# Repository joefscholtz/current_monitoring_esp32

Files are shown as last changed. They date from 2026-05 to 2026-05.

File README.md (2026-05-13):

# current_monitoring_esp32

Modular firmware project in PlatformIO and hardware design in KiCad using ESP32 and ESP-IDF framework for measuring current and detecting leakage using CT sensors, publishing the data via MQTT through Wifi ( and Ethernet, but not yet fully implemented ). For more informatation on design decisions consult the `docs` directory.

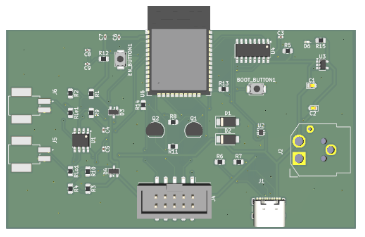
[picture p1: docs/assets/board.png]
Custom ESP32-WROOM-32E Board


## Project structure

```
.
├── .github/workflows/          # CI/CD
├── app/                        # Two alternatives to consume the library
│   ├── bare_metal/             # Simple Super-Loop implementation
│   └── rtos/                   # RTOS Task-based
├── components/                 # Library ESP-IDF style components
│   └── current_monitor/        # RMS, Differential math, Calibration
│   └── network_manager/        # Wifi, Ethernet and MQTT
├── docs/                       # Documentation
├── kicad/                      # KiCad files
│   └── current_monitor_board/  # KiCad project
│   └── mods/                   # KiCad libraries
├── scripts/                    # Scripts for the project
├── test/                       # Unit tests for the monitor library
├── platformio.ini              # Multi-environment config
├── wokwi.toml                  # Simulation config for ESP32 + Sensors
└── diagram.json                # Wokwi hardware layout
```

## Installation

### With Docker

Requirements:

- Docker
- Docker Compose
- just (Optional)

using just:

```bash
just dev init
```

without just

```bash
DOCKER_COMPOSE_SERVICE=current_monitoring_esp32-app

docker-compose run --rm $DOCKER_COMPOSE_SERVICE just init
```

### Without Docker:

Requirements:

- uv (Python manager)
- PlatformIO CLI
- Wokwi (Optional, needed for simulation)
- just (Optional)

using just:

```bash
just init
```

without just

```bash
uv sync
uv run pio run -t compiledb
```

### Git hooks

using uv and just

```bash
just pre-commit-init
```

using only uv

```bash
uv run pre-commit install --hook-type pre-commit --hook-type pre-push
```

and it can also be installed using only Python.

## Build

### With Docker

using just:

```bash
just dev build
```

without just

```bash
DOCKER_COMPOSE_SERVICE=current_monitoring_esp32-app

docker-compose run --rm $DOCKER_COMPOSE_SERVICE just build
```

### Without Docker:

using just:

```bash
just build
```

without just

```bash
uv run pio run -e bare_metal -e rtos
```

## Flash

...

## TODO

### current_monitor:

- [x] Acquisition interval missed
- [x] Convert raw into voltage
- [x] Calibration
- [ ] Move pin definitions to Kconfig
- [ ] Check `MAX_DIGI_VALUE`

### mqtt:

### App:

### Flash

- [ ] Add flash scripts
- [ ] efuse
- [ ] self-contained flash script

### Docs:

- [x] Hardware mapping
- [x] C4 model

### KiCad

- [ ] MQTT thru Ethernet

### Other:

- [x] Test with PlatformIO IDE
- [ ] Run Tests without `static inline` functions

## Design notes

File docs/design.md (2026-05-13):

## Design Documentation

## 1. System Architecture

```mermaid
C4Container
    title Container & Hardware Interaction Diagram

    %% Physical Hardware Layer
    System_Boundary(hw, "Physical Hardware") {
        Container(leakage_ct, "CT 2000:1 (Leakage)", "Hardware", "GPIO 34 (ADC1_CH6) + 22k Burden")
        Container(load_ct, "CT 1000:1 (Load)", "Hardware", "GPIO 35 (ADC1_CH7) + 100R Burden")
        Container(eth_chip, "DISABLED: ENC28J60 (Ethernet)", "SPI Peripheral", "GPIO 18, 19, 23 (VSPI)")
    }

    %% Firmware Layer
    Container_Boundary(esp32, "ESP32 Firmware") {

        Container_Boundary(core1, "Core 1 (Sensing)") {
            Container(sensor_task, "Sensor Task", "FreeRTOS", "vTaskDelayUntil (300ms frequency)")
            Container(cm_comp, "Current Monitor", "IDF Component", "ADC1 Drivers + RMS Engine")
        }

        Container_Boundary(core0, "Core 0 (Networking)") {
            Container(network_task, "Network Task", "FreeRTOS", "Asynchronous MQTT Client")
            Container(nm_comp, "Network Manager", "IDF Component", "WiFi/ETH/MQTT Handlers")
        }

        ContainerDb(queue, "Data Queue", "FreeRTOS Queue", "Current_readings_t (inc. Timestamp)")
    }

    %% Relationships
    Rel(leakage_ct, cm_comp, "Analog Signal", "Voltage (0-3.3V)")
    Rel(load_ct, cm_comp, "Analog Signal", "Voltage (0-3.3V)")
    Rel(sensor_task, cm_comp, "Reads Raw/RMS", "API Call")
    Rel(sensor_task, queue, "Pushes Data", "Queue Send (Non-blocking)")

    Rel(queue, network_task, "Pops Data", "Queue Receive (Blocking)")
    Rel(network_task, nm_comp, "Triggers Pub", "API Call")
    Rel(nm_comp, eth_chip, "SPI Commands", "VSPI Bus")
```

## 2. Hardware Mapping:

The system is designed for the ESP32-WROOM-32 (30 or 38 pin DevKit). The following pins were selected based on their peripheral capabilities (ADC1 vs ADC2) availability.

| Component | GPIO | Peripheral | Function | Logic / Signal |
| --- | ---- | --- | --- | --- |
| Leakage CT | 34 | ADC1_CH6 | Analog Input | AC signal + 1.65V Bias |
| Load CT | 35 | ADC1_CH7 | Analog Input | AC signal + 1.65V Bias |
| V_Ref Monitor | 32 | ADC1_CH4 | Analog Input | 1.65V DC Mid-rail (Calibration) |

## 3. Design Decisions

### 3.1 RMS Sampling Strategy

To meet the 300ms maximum interval requirement, the firmware implements a high-frequency sampling window:

- Sampling Frequency: ~5-10kHz per channel to accurately capture 60Hz waveforms.
- RMS Calculation: Discrete-time True RMS calculation is performed: $V_{rms} = \sqrt{\frac{1}{N} \sum_{i=1}^{N} (v_i - V_{offset})^2}$
- Fixed Frequency: Using `vTaskDelayUntil` ensures the 300ms deadline is strictly met regardless of calculation overhead, avoiding drift.

### 3.2 Noise Handling

- Hardware Offset: A 1.65V DC bias is applied to the CT signal to allow the ESP32 (0-3.3V range) to sample the AC negative half-cycle.
- Software Filtering:
  - Deadzone: A small software threshold is applied to eliminate "ghost" readings caused by ADC noise floor.
  - Averaging: Multiple samples are accumulated per window to smooth out transient spikes.
  - Hardware Calibration: ADC calibration to mitigate chip-to-chip gain errors.

### 3.3 Software Architecture

- Modular Component Architecture: Logic is segregated into reusable, standalone components (`current_monitor`, `network_manager`) to minimize coupling and facilitate parallel testing.
- Provider/Consumer Model: The `apps/` act as consumers of the `components/` provider library. This allows the same hardware-interfacing code to be reused across different execution models (Bare-Metal Super-Loop vs. RTOS Preemptive Tasks).
- Opaque Handle Pattern: By using pointer-based handles for component initialization and interaction, the internal structures remain protected from the application layer, reducing the risk of accidental memory corruption.
- Decoupling (Dual-Core): Sampling is pinned to Core 1 to ensure zero jitter.
- Networking (WiFi/MQTT) is pinned to Core 0 to handle the non-deterministic TCP/IP stack.
- Unified Identity: Both Wi-Fi and Ethernet (Ethernet not fully implemented) use the internal Factory MAC as the MQTT Client ID, ensuring the backend treats the device as a single entity regardless of the physical connection.

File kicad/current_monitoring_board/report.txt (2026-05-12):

Annotated USB_C_Receptacle_USB2.0_16P as J1.
Annotated 100k as R5.
Annotated 100k as R4.
Annotated 100k as R3.
Annotated 100k as R2.
Annotated 100k as R1.
Annotated S8050 as Q2.
Annotated S8050 as Q1.
Annotated Microsemi_FlashPro-JTAG-10 as J4.
Annotated RJ45_Hanrun_HR911105A_Horizontal as J3.
Annotated CUI_PD-30 as J2.
Annotated 5.1k as R6.
Annotated BAT54S as D4.
Annotated BAT54S as D3.
Annotated SS14 as D2.
Annotated SS14 as D1.
Annotated 100nF as C9.
Annotated 100uF as C8.
Annotated 100nF as C7.
Annotated 22uF as C6.
Annotated 10nF as C5.
Annotated 10nF as C4.
Annotated TS-1088-AR02016 as S1.
Annotated ASV-50.000MHz as Y1.
Annotated ESP32-WROOM-32E as U6.
Annotated LAN8720A as U5.
Annotated OPA2333xxD (unit C) as U1C.
Annotated CH340C as U4.
Annotated AP2112K-3.3 as U3.
Annotated USBLC6-2P6 as U2.
Annotated OPA2333xxD (unit B) as U1B.
Annotated OPA2333xxD (unit A) as U1A.
Annotated TS-1088-AR02016 as S2.
Annotated 10u as C3.
Annotated 100 as RLo1.
Annotated 22k as RLe1.
Annotated 10k as R14.
Annotated 100 as R13.
Annotated 10k as R12.
Annotated 10k as R11.
Annotated 100 as R10.
Annotated 100 as R9.
Annotated 10k as R8.
Annotated 5.1k as R7.
Annotated GND as #PWR012.
Annotated GND as #PWR022.
Annotated +5V as #PWR021.
Annotated +5V as #PWR020.
Annotated +3.3V as #PWR019.
Annotated +3.3V as #PWR018.
Annotated GND as #PWR017.
Annotated GND as #PWR016.
Annotated +3.3V as #PWR015.
Annotated GND as #PWR014.
Annotated GND as #PWR013.
Annotated +5V as #PWR023.
Annotated GND as #PWR011.
Annotated +5V as #PWR010.
Annotated GND as #PWR09.
Annotated +5V as #PWR08.
Annotated +5V as #PWR07.
Annotated GND as #PWR06.
Annotated +5V as #PWR05.
Annotated GND as #PWR04.
Annotated +3.3V as #PWR03.
Annotated GND as #PWR02.
Annotated GND as #PWR034.
Annotated TCJB226M025R0150E as C2.
Annotated TCJB226M025R0150E as C1.
Annotated GND as #PWR042.
Annotated +3.3V as #PWR041.
Annotated GND as #PWR040.
Annotated GND as #PWR039.
Annotated GND as #PWR038.
Annotated +3.3V as #PWR037.
Annotated GND as #PWR036.
Annotated +3.3V as #PWR035.
Annotated +3.3V as #PWR01.
Annotated +3.3V as #PWR033.
Annotated GND as #PWR032.
Annotated +3.3V as #PWR031.
Annotated GND as #PWR030.
Annotated GND as #PWR029.
Annotated GND as #PWR028.
Annotated +5V as #PWR027.
Annotated GND as #PWR026.
Annotated GND as #PWR025.
Annotated GND as #PWR024.
Annotation complete.

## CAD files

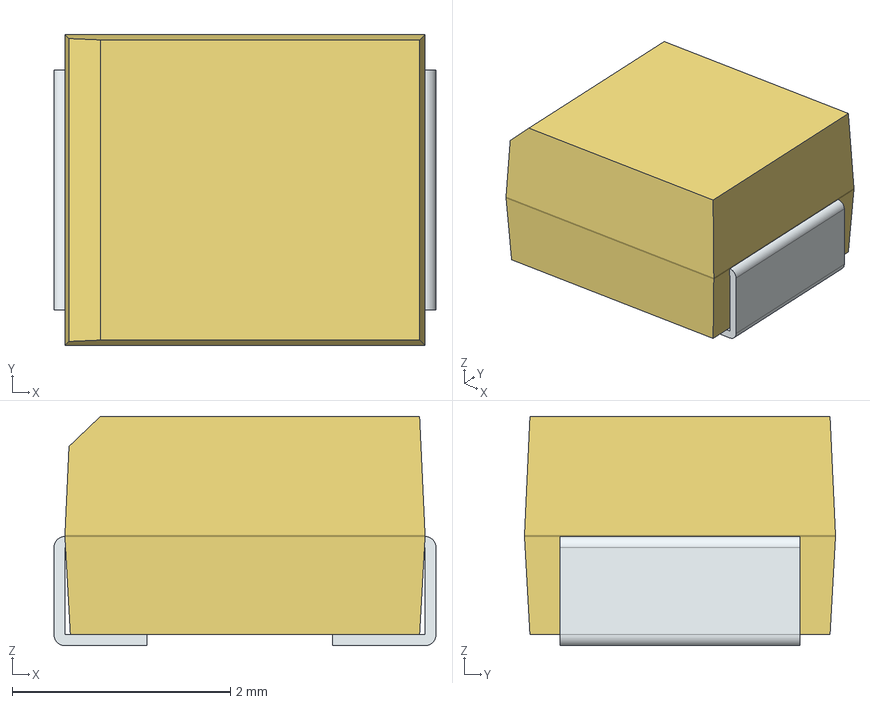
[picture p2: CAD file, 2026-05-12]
kicad/mods/TCJB226M025R0150E/3D/TCJB226M025R0150E.stp
3.50 x 2.85 x 2.10 mm
FilletPin1
FilletPin2

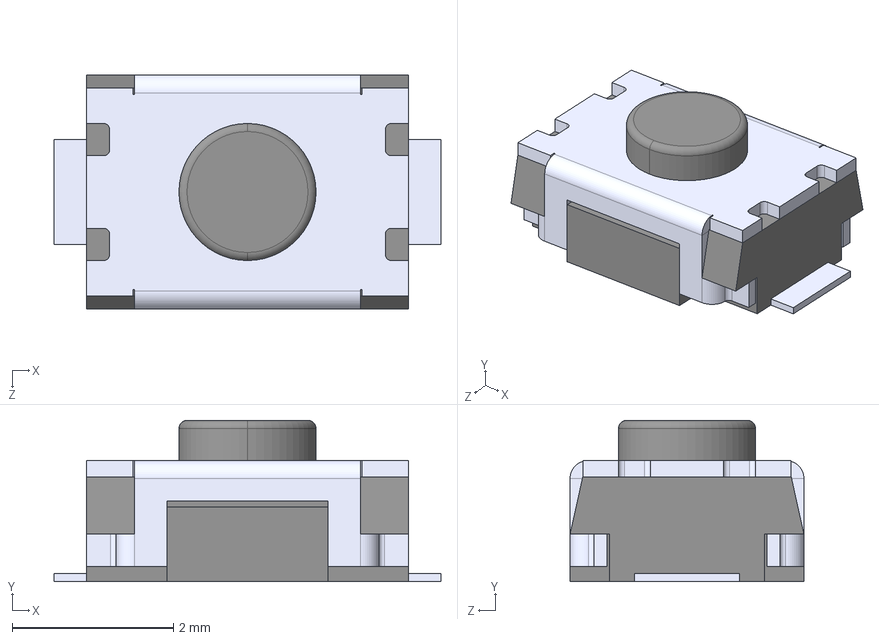
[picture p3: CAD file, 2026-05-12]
kicad/mods/TS-1088-AR02016/TS-1088-AR02016.step
4.80 x 2.00 x 2.90 mm

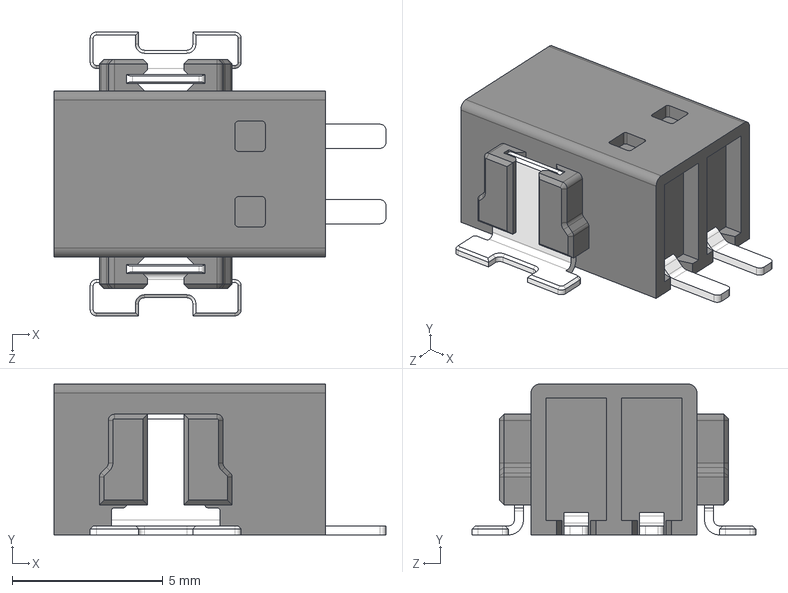
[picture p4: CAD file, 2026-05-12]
kicad/mods/ptsm_0_5_2_2_5_h_smd_r_24/1702473.step
11.0 x 5.00 x 9.40 mm

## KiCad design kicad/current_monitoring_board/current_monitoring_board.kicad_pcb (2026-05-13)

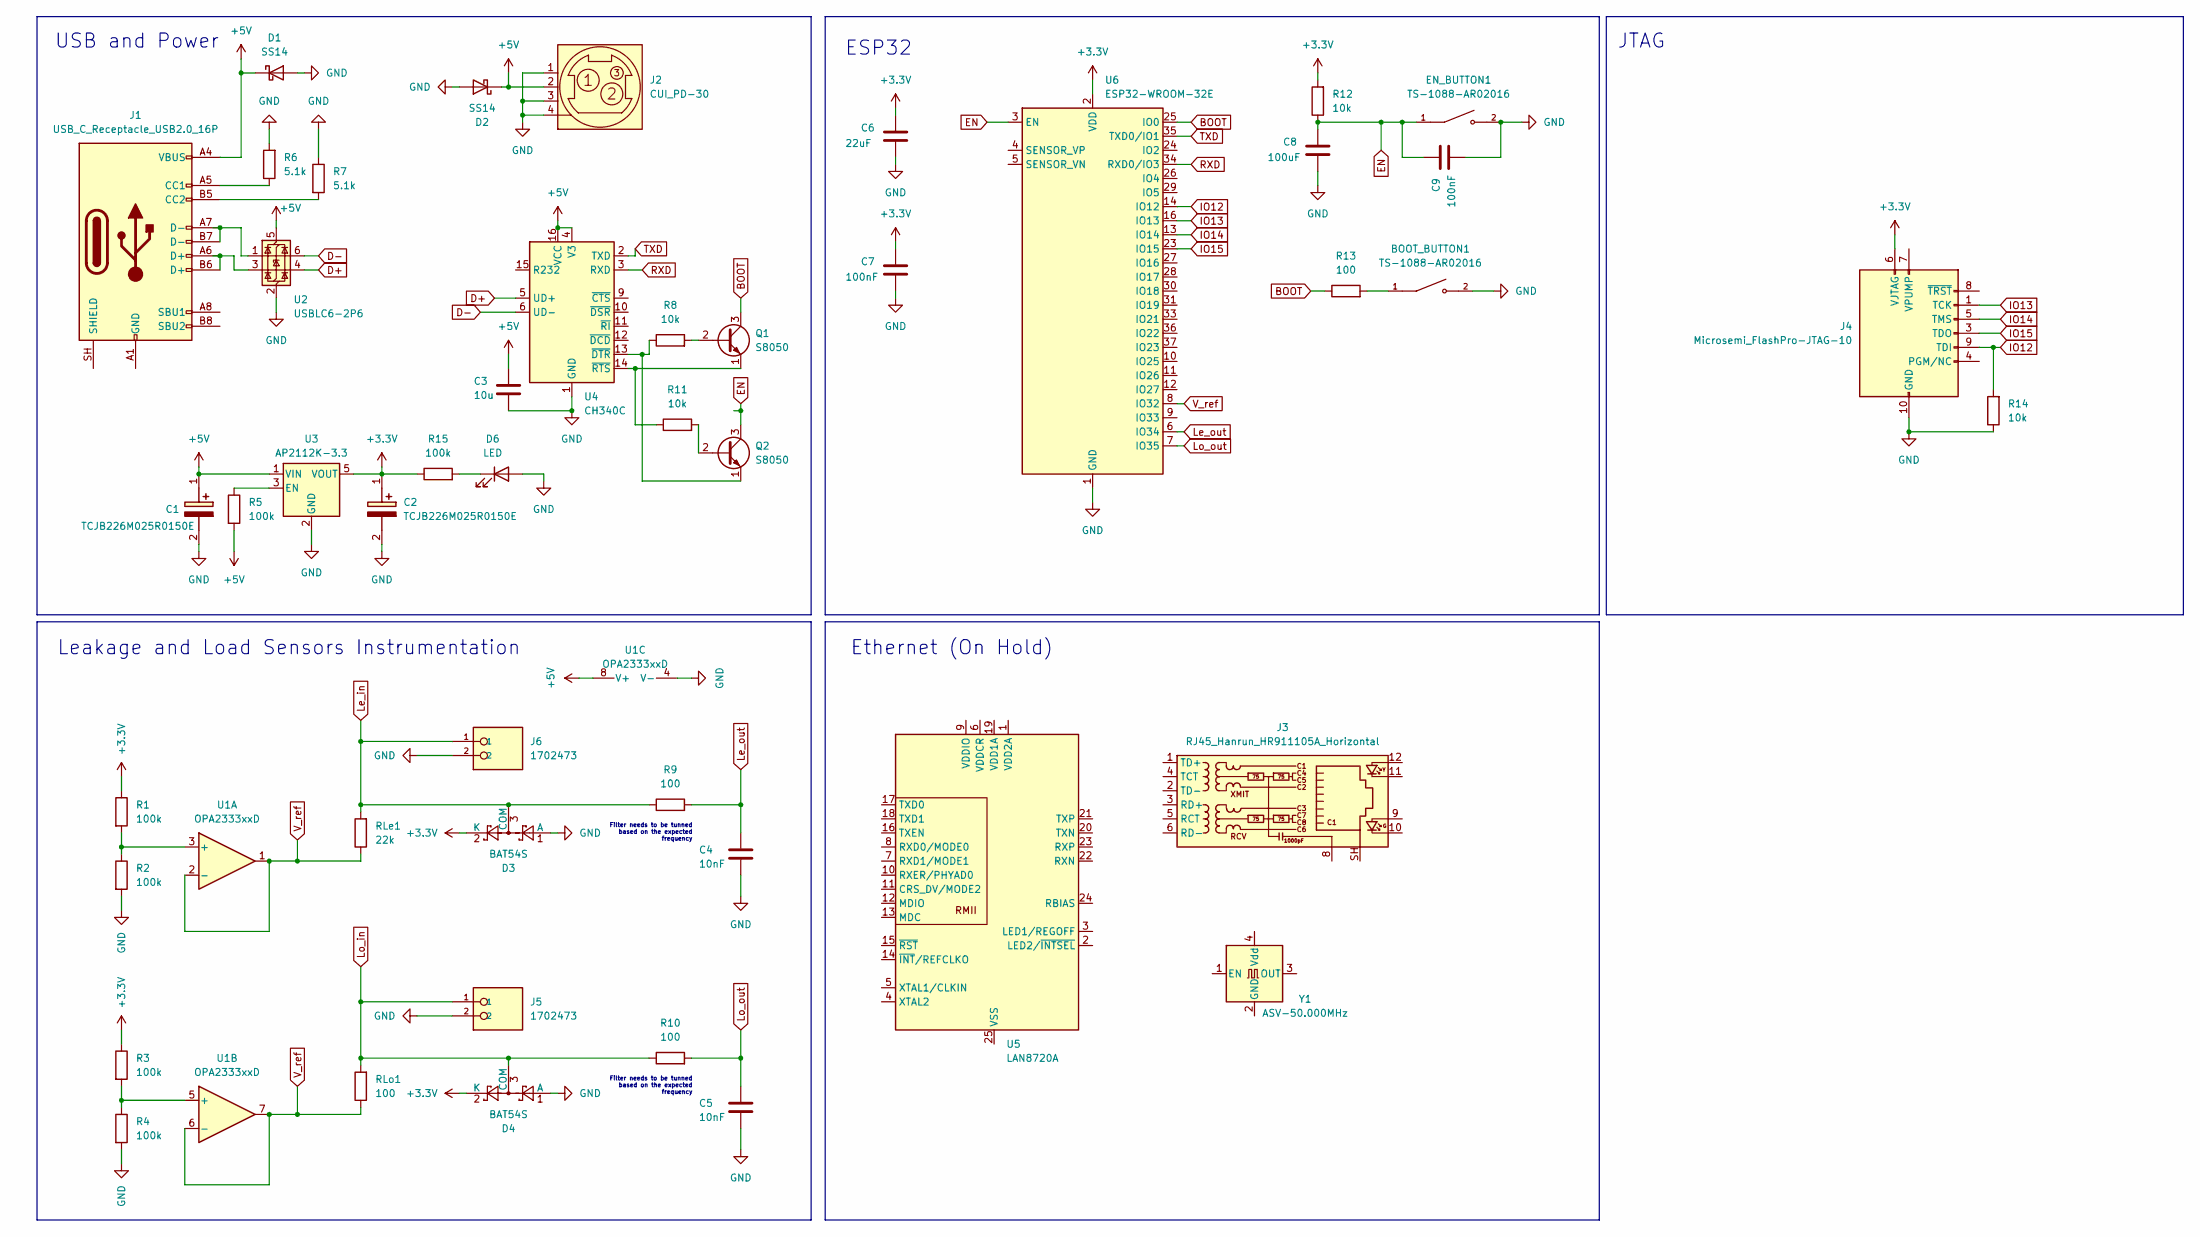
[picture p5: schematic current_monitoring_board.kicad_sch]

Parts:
BOOT_BUTTON1: TS-1088-AR02016; SW_SPST_TS-1088-xR020; PARTREV N/A
C1, C2: TCJB226M025R0150E; CP_EIA-1608-08_AVX-J; Mouser Part Number 581-CJB226M025R0150E
C3: 10u; C_0402_1005Metric
C4, C5: 10nF; C_0402_1005Metric
C6: 22uF; C_0402_1005Metric
C7, C9: 100nF; C_0402_1005Metric
C8: 100uF; C_0402_1005Metric
D1, D2: SS14; D_SMA
D3, D4: BAT54S; SOT-23
D6: LED; LED_0402_1005Metric
EN_BUTTON1: TS-1088-AR02016; SW_SPST_TS-1088-xR020; PARTREV N/A
J1: USB_C_Receptacle_USB2.0_16P; USB_C_Receptacle_GCT_USB4105-xx-A_16P_TopMnt_Horizontal
J2: CUI_PD-30
J3: RJ45_Hanrun_HR911105A_Horizontal
J4: Microsemi_FlashPro-JTAG-10; IDC-Header_2x05_P2.54mm_Vertical_SMD
J5, J6: 1702473; PHOENIX_1702473; PARTREV 09.11.2015
Q1, Q2: S8050; TO-92_Inline
R1, R2, R3, R4, R5, R15: 100k; R_0805_2012Metric
R6, R7: 5.1k; R_0805_2012Metric
R8, R11, R12, R14: 10k; R_0805_2012Metric
R9, R10, R13: 100; R_0805_2012Metric
RLe1: 22k; R_0805_2012Metric
RLo1: 100; R_0805_2012Metric
U1: OPA2333xxD; SOIC-8_3.9x4.9mm_P1.27mm
U2: USBLC6-2P6; SOT-666
U3: AP2112K-3.3; SOT-23-5
U4: CH340C; SOIC-16_3.9x9.9mm_P1.27mm
U5: LAN8720A; QFN-24-1EP_4x4mm_P0.5mm_EP2.6x2.6mm
U6: ESP32-WROOM-32E
Y1: ASV-50.000MHz; Oscillator_SMD_Abracon_ASV-4Pin_7.0x5.1mm

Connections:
+3.3V: C2.1 (+), C6.1, C7.1, D3.2 (K), D4.2 (K), J4.6 (VJTAG), R1.1, R3.1, R12.2, R15.1, U3.5 (VOUT), U6.2 (VDD)
+5V: C1.1 (+), C3.1, D1.1 (K), D2.1 (K), J1.A4 (VBUS), J1.A9 (VBUS), J1.B4 (VBUS), J1.B9 (VBUS), J2.2, R5.2, U1.8 (V+), U2.5 (VBUS), U3.1 (VIN), U4.4 (V3), U4.16 (VCC)
BOOT: Q1.3 (C), R13.1, U6.25 (IO0)
D+: U2.4 (I/O2), U4.5 (UD+)
D-: U2.6 (I/O1), U4.6 (UD-)
EN: C8.1, C9.1, EN_BUTTON1.1, Q2.3 (C), R12.1, U6.3 (EN)
GND: BOOT_BUTTON1.2, C1.2 (-), C2.2 (-), C3.2, C4.2, C5.2, C6.2, C7.2, C8.2, C9.2, D1.2 (A), D2.2 (A), D3.1 (A), D4.1 (A), D6.2 (A), EN_BUTTON1.2, J2.1, J2.3, J2.4 (Shield), J4.2 (GND), J4.10 (GND), J5.2, J6.2, R2.2, R4.2, R6.2, R7.1, R14.1, U1.4 (V-), U2.2 (GND), U3.2 (GND), U4.1 (GND), U6.1 (GND), U6.15 (GND), U6.38 (GND), U6.39 (GND)
IO12: J4.9 (TDI), R14.2, U6.14 (IO12)
IO13: J4.1 (TCK), U6.16 (IO13)
IO14: J4.5 (TMS), U6.13 (IO14)
IO15: J4.3 (TDO), U6.23 (IO15)
Le_in: D3.3 (COM), J6.1, R9.1, RLe1.2
Le_out: C4.1, R9.2, U6.6 (IO34)
Lo_in: D4.3 (COM), J5.1, R10.1, RLo1.2
Lo_out: C5.1, R10.2, U6.7 (IO35)
unnamed: BOOT_BUTTON1.1, R13.2
unnamed: D6.1 (K), R15.2
unnamed: J1.A5 (CC1), R6.1
unnamed: J1.B5 (CC2), R7.2
unnamed: J1.A6 (D+), J1.B6 (D+), U2.3 (I/O2)
unnamed: J1.A7 (D-), J1.B7 (D-), U2.1 (I/O1)
unnamed: J1.A1 (GND), J1.A12 (GND), J1.B1 (GND), J1.B12 (GND)
unnamed: Q1.2 (B), R8.2
unnamed: Q1.1 (E), R11.1, U4.14 (~RTS)
unnamed: Q2.2 (B), R11.2
unnamed: Q2.1 (E), R8.1, U4.13 (~DTR)
unnamed: R1.2, R2.1, U1.3 (+)
unnamed: R3.2, R4.1, U1.5 (+)
unnamed: R5.1, U3.3 (EN)
RXD: U4.3 (RXD), U6.34 (RXD0/IO3)
TXD: U4.2 (TXD), U6.35 (TXD0/IO1)
V_ref: RLe1.1, RLo1.1, U1.1, U1.2 (-), U1.6 (-), U1.7, U6.8 (IO32)

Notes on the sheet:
Ethernet (On Hold)
Filter needs to be tunned based on the expected frequency
ESP32
Leakage and Load Sensors Instrumentation
USB and Power
JTAG

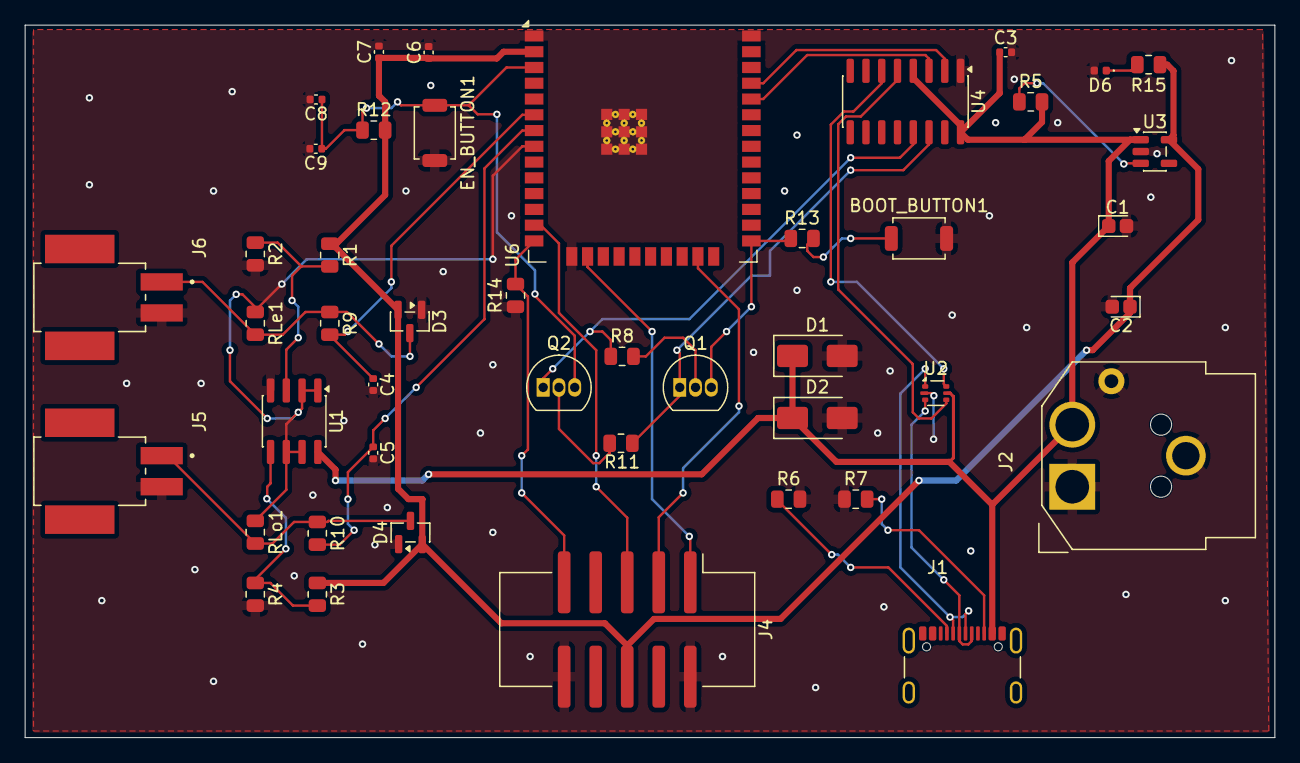
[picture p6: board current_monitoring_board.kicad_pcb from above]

Board: 2 copper layers, 100.7 x 57.4 mm, 45 parts (0 on the bottom side), 32 nets.

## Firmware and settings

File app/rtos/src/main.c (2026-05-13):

#include "current_monitor.h"
#include "esp_log.h"
#include "esp_rom_serial_output.h"
#include "freertos/FreeRTOS.h"
#include "freertos/queue.h"
#include "freertos/task.h"
#include "network_manager.h"
#include <stdio.h>
#include <sys/time.h>

static const char *TAG = "RTOS_APP";

static QueueHandle_t data_queue;

void vSensorProcessingTask(void *pvParameters) {
  current_monitor_handle_t *monitor = (current_monitor_handle_t *)pvParameters;

  TickType_t xLastWakeTime = xTaskGetTickCount();
  const TickType_t xFrequency = pdMS_TO_TICKS(TOTAL_LOOP_MS);

  int task_should_run = 1;
  while (task_should_run) {
    vTaskDelayUntil(&xLastWakeTime, xFrequency);

    current_readings_t readings = current_monitor_get_readings(monitor);

    struct timeval tv;
    gettimeofday(&tv, NULL);
    readings.timestamp_ms =
        (uint64_t)tv.tv_sec * 1000LL + (uint64_t)tv.tv_usec / 1000LL;

    xQueueSend(data_queue, &readings, 0);
  }
  current_monitor_deinit(monitor);
  vTaskDelete(NULL);
}

void vNetworkTask(void *pvParameters) {
  network_manager_t *net_mgr = (network_manager_t *)pvParameters;
  current_readings_t data;
  char payload_buffer[200];

  int task_should_run = 1;
  while (task_should_run) {
    if (xQueueReceive(data_queue, &data, portMAX_DELAY)) {
      if (network_is_connected(net_mgr)) {
        current_monitor_readings_to_str(&data, payload_buffer,
                                        sizeof(payload_buffer));
        network_mqtt_publish(net_mgr, CONFIG_MQTT_TOPIC, payload_buffer);
        ESP_LOGD(TAG, "Published: %s", payload_buffer);
      }
    }
  }
  network_manager_destroy(net_mgr);
  vTaskDelete(NULL);
}

void app_main(void) {
  data_queue = xQueueCreate(10, sizeof(current_readings_t));

  current_reading_config_t vref_cfg = {.adc_unit_id = ADC_UNIT_1,
                                       .adc_channel_id = ADC_CHANNEL_4};
  current_reading_config_t leakage_cfg = {.adc_unit_id = ADC_UNIT_1,
                                          .adc_channel_id = ADC_CHANNEL_6};
  current_reading_config_t load_cfg = {.adc_unit_id = ADC_UNIT_1,
                                       .adc_channel_id = ADC_CHANNEL_7};

  current_monitor_handle_t *monitor =
      current_monitor_init(vref_cfg, leakage_cfg, load_cfg);
  monitor->vref_enabled = true;
  monitor->cali_enabled = true;

  if (current_monitor_begin(monitor) != ESP_OK) {
    ESP_LOGE(TAG, "Failed to initialize sensors");
    return;
  }

  xTaskCreatePinnedToCore(
      vSensorProcessingTask, "SensorMonitor", 4096, (void *)monitor,
      configMAX_PRIORITIES - 1, // high priority to minimize jitter
      NULL, 1);

  esp_rom_printf("\n--- ROM PRINT: RTOS Task Started ---\n");
  printf("RTOS Task Started\n");

  ESP_LOGI(TAG, "Sensor task spawned on Core 1.");

  network_manager_t *net_mgr =
      network_manager_create(NET_INTERFACE_WIFI, CONFIG_MQTT_BROKER_URL);
  ESP_ERROR_CHECK(network_manager_init(net_mgr));

  xTaskCreatePinnedToCore(vNetworkTask, "Network", 4096, (void *)net_mgr,
                          configMAX_PRIORITIES - 2, NULL, 0);
}

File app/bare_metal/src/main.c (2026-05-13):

#include "current_monitor.h"
#include "esp_log.h"
#include "freertos/FreeRTOS.h"
#include "freertos/task.h"
#include "network_manager.h"

static const char *TAG = "BARE_METAL";

void app_main(void) {
  current_reading_config_t vref_cfg = {.adc_unit_id = ADC_UNIT_1,
                                       .adc_channel_id = ADC_CHANNEL_4};
  current_reading_config_t leakage_cfg = {.adc_unit_id = ADC_UNIT_1,
                                          .adc_channel_id = ADC_CHANNEL_6};
  current_reading_config_t load_cfg = {.adc_unit_id = ADC_UNIT_1,
                                       .adc_channel_id = ADC_CHANNEL_7};

  current_monitor_handle_t *monitor =
      current_monitor_init(vref_cfg, leakage_cfg, load_cfg);
  monitor->vref_enabled = true;
  monitor->cali_enabled = true;

  if (current_monitor_begin(monitor) != ESP_OK) {
    ESP_LOGE(TAG, "Failed to initialize sensors");
    return;
  }
  network_manager_t *net_mgr =
      network_manager_create(NET_INTERFACE_WIFI, CONFIG_MQTT_BROKER_URL);
  ESP_ERROR_CHECK(network_manager_init(net_mgr));

  ESP_LOGI(TAG, "Starting Bare-Metal Super-Loop...");

  int task_should_run = 1;
  while (task_should_run) {
    TickType_t start_tick = xTaskGetTickCount();
    current_readings_t data = current_monitor_get_readings(monitor);
    char payload_buffer[200];

    ESP_LOGI(TAG, "Leakage RMS: %.2f | Load RMS: %.2f", data.leakage_rms,
             data.load_rms);

    current_monitor_readings_to_str(&data, payload_buffer,
                                    sizeof(payload_buffer));

    if (network_is_connected(net_mgr)) {
      network_mqtt_publish(net_mgr, CONFIG_MQTT_TOPIC, payload_buffer);
    }

    vTaskDelayUntil(&start_tick, pdMS_TO_TICKS(TOTAL_LOOP_MS));
  }
  current_monitor_deinit(monitor);
  network_manager_destroy(net_mgr);
}

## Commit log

2026-05-08 start versioning kicad files
    [TCJB226M025R0150E.stp, current_monitoring_board.kicad_pcb, current_monitoring_board.kicad_sch]
2026-05-09 first version of pcb
    [1702473.step, TS-1088-AR02016.step, current_monitoring_board.kicad_pcb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]
2026-05-12 boilerplate for bare_metal and rtos using current_monitor component
2026-05-12 local ci in different stages
2026-05-12 update build image driver
2026-05-12 update README after first current_monitor version
2026-05-13 update board image
2026-05-13 refactor calibration
2026-05-13 update vref vias
    [current_monitoring_board.kicad_pcb]
